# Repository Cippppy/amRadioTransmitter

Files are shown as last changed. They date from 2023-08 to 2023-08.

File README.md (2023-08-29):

# AM Radio Transmitter
This was the final project done for Electronics I by Christian Cipolletta and Thomas Rasa. It is a radio transmitter that will broadcast in the AM band. It uses a Gilbert cell circuit for the mixer, a differential amplifier to combine and strengthen the signal, and an antenna to broadcast it. There is also an MSP430FR2355 Launchpad evaluation board that adds the functionality of changing the tone being broadcast.

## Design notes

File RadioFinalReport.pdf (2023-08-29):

### AM Radio Transmitter: A Gilbert Cell, an Operational Amplifier, and an Antenna

Christian Cipolletta, Thomas Rasa
May 2023

Abstract
This application note described the creation and successful use of an AM radio transmitter circuit. It uses a gilbert cell and a differential amplifier to generate and transmit AM radio waves. The circuit was successful in its simulation and in its prototyping. However, the completed project has a large room for improvement.

Background
The radio is a century old invention that allows for wireless communication by using radio waves. There are two types of waves, amplitude modulation (AM) and frequency modulation (FM). The difference between the two is how the sound information is carried. In the AM band, this is done by varying the amplitude of the signal while in the FM band it is done by varying the frequency of the signal. For this project, we will be focusing on the AM band. There are numerous ways to create a radio transmitter. The one used for this project is a heterodyne transmitter shown in figure
1. A heterodyne is a signal that gets created when mixing two frequencies together. The full circuit includes a low-pass filter (LPF), two amplifiers, the mixer, a bandpass filter (BPF) and an antenna.

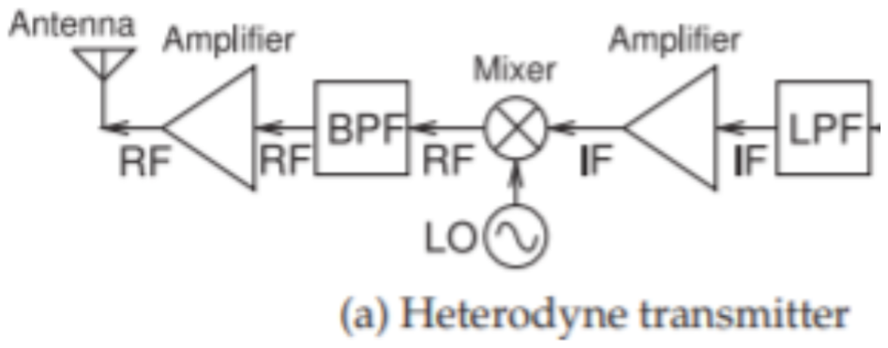
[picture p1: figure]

Figure 1. Heterodyne Transmitter Circuit

For the mixer, we created a circuit called a Gilbert Cell. A Gilbert Cell will create output signals that are proportional to the product of two input signals, which is a different way of saying that it will mix them together. It uses resistors, transistors, and capacitors to create this affect as shown in figure 2. The transfer function of a Gilbert cell is as shown in equation 2

V | (1)

### out = S(ωt) * B(ωt)

Where:
B is the baseband carrier signal
S is the modulating frequency

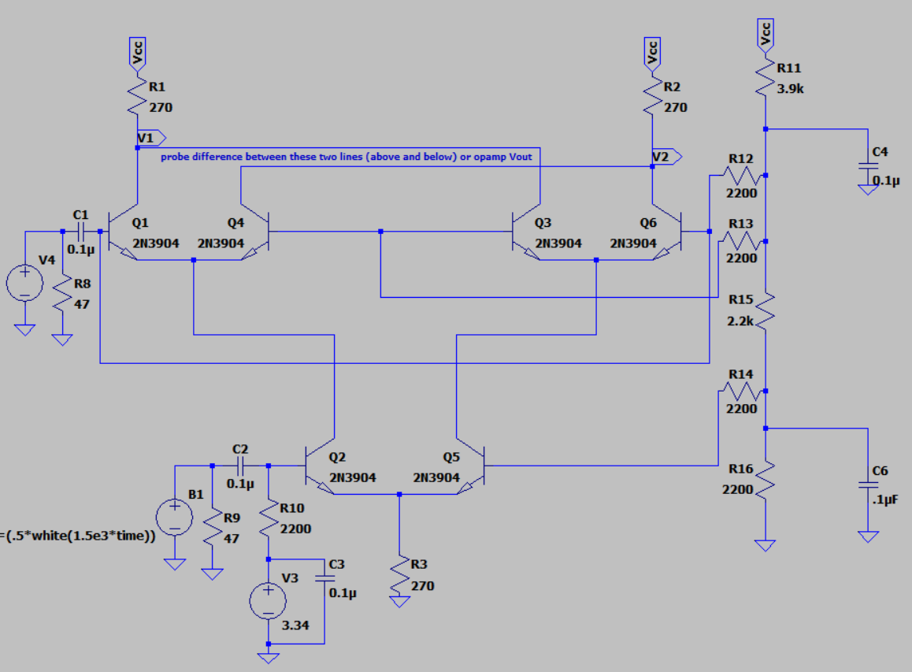
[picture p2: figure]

Figure 2. Gilbert Cell Schematic

For the amplifier circuit, we used a differential operational amplifier topology. In figure 3, R6 and R7 were the same value, and R4 and R5 were the same value to simplify the equation for the gain. This is shown in equation 2.

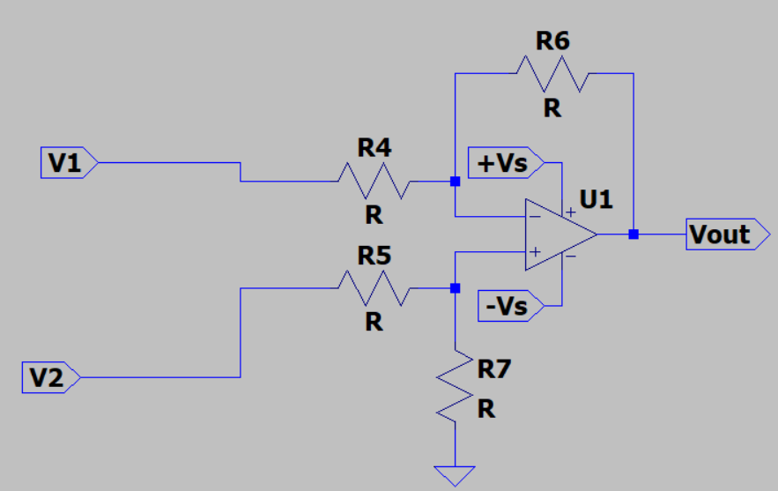
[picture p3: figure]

Figure 3. Dif erential Amplifier Schematic

V

out = (R
3

/R
1

)(V

2 − V
1

)

(2)
Design Constraints
This circuit could be constructed with ease if the world had unlimited resources and each piece was ideal. However, the world is not ideal, so there are constraints that had to be followed when creating this system. First, the system had to be run off of 12VDC or less for safety reasons. Second, it had to have an array of electronic components, specifically modern ones. Third, it had to be low power. Fourth, it had to have a mixed signal/embedded element. Overall, the system had to be edited and unique to fit within these specifications.
One way we fit these constraints is by using an MSP430FR2355 Launch Pad from TI (figure 4). This embedded system would allow us to easily adjust the modulating signal of the AM wave. We used it to specifically make 10 different musical notes that could be played at the touch of a button.

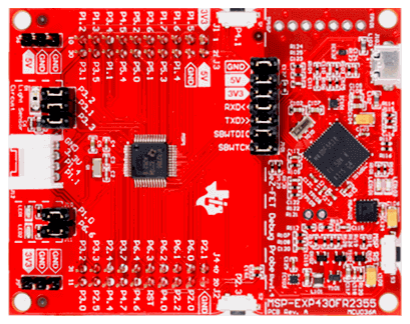
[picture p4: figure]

Figure 4. MSP430FR2355 Launchpad

Approach
The first step of this experiment was to simulate the circuits. It is essential to make sure that the theory works. We did this using the program LTSPICE. We created schematics of each component of the transmitter to ensure that we would be able to get the output signals we expected. This also allowed us to vary any values to see what could be changed in our designs if issues arise later in the process.
The second step is to prototype. We used both bread boards and protoboards to recreate the circuits in real life. Utilizing an oscilloscope, function generator, and power supply we tried to see if the LTSPICE results could be recreated.
The third step was to take any successes from the prototype and redraw the schematic. If there were issues found or improvements that could be made, we made the changes and then re-drew the schematics to make sure the changes were reflected there. With this new schematic, we created a printed circuit board (PCB) that networked all the needed components of the system. The last step was to build and test the PCB. After creating the PCB schematic using a software named Altium, we sent out files to a PCB manufacturer. Once the PCB was received we could then solder all the components onto the PCB. After soldering was completed the radio was ready for final testing.

Results
The results of the LTSPICE simulation are shown in figures 5, 6, and 7. The green and blue plots are the outputs of the gilbert cell circuit. They form a nice radio wave as expected. The red plot is the output of the differential amplifier. It is what is the final signal that would be transmitted to radio receivers.

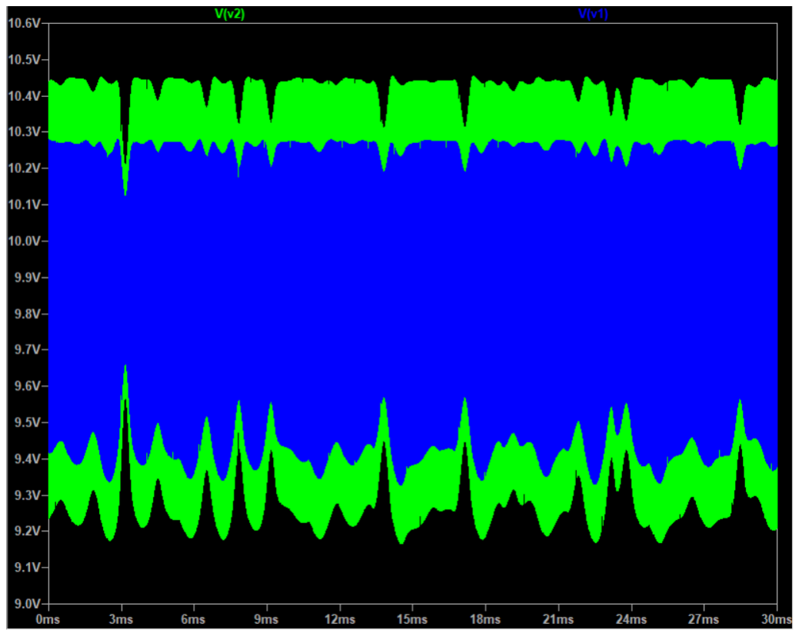
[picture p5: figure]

Figure 5. LTSPICE output of gilbert cell circuit

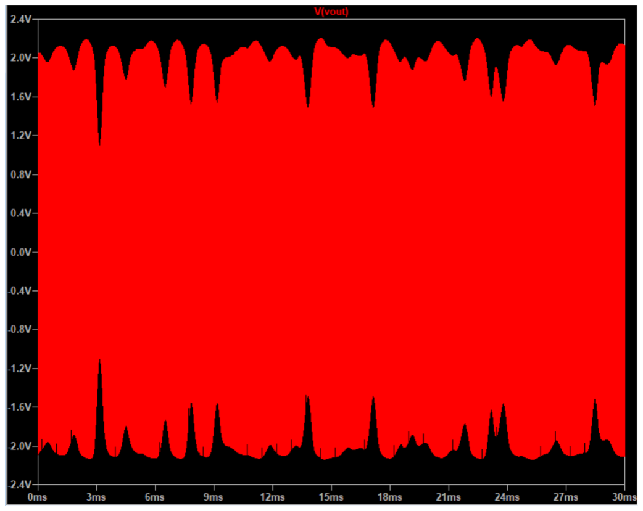
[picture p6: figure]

Figure 6. LTSPICE output of dif erential amplifier

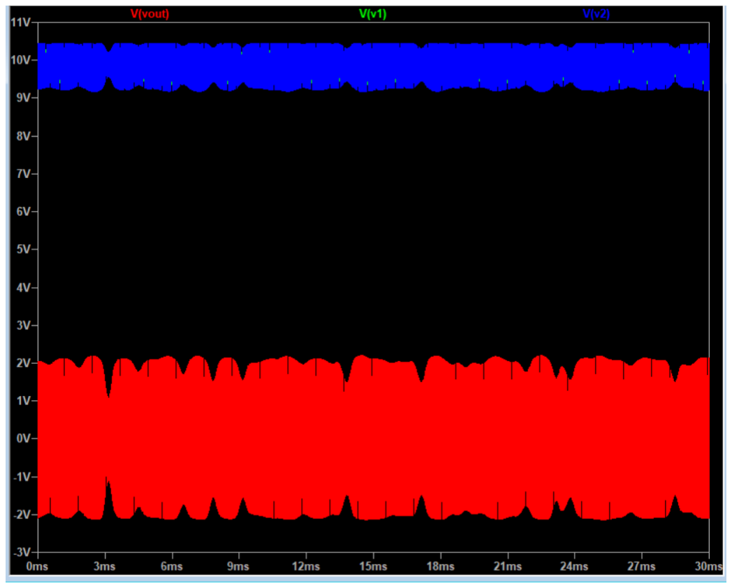
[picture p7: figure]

Figure 7. Combined LTSPICE output

Results from the breadboard prototype of the gilbert cell circuit are shown in figure 8. This also is the expected result. It gives a waveform that is characteristic of AM radio waves. The results from the differential amplifier were not pictured, but they were as expected too.

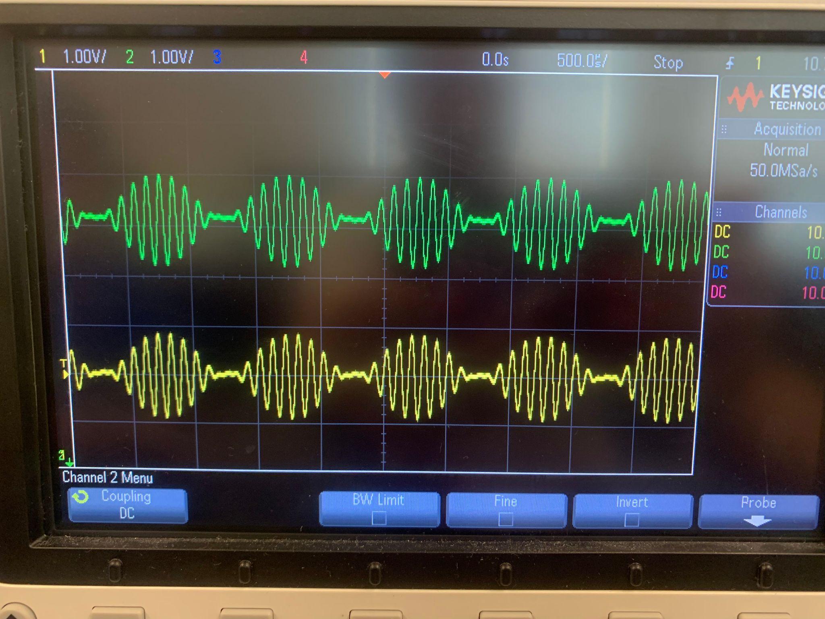
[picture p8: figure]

Figure 8. Prototype Output on oscilloscope

The fully soldered PCB is shown in figure 9. The gilbert cell circuit is soldered at the bottom of the PCB along with the operational amplifier. The potentiometer at the top of the board is there to try and create an offset for the unipolar op-amp we created. The jumpers are where we are able to hook up external function generators, power supplies, and the MSP430. The last part of the board, located at the bottom, is a coaxial SMA hookup that connects to the antenna.

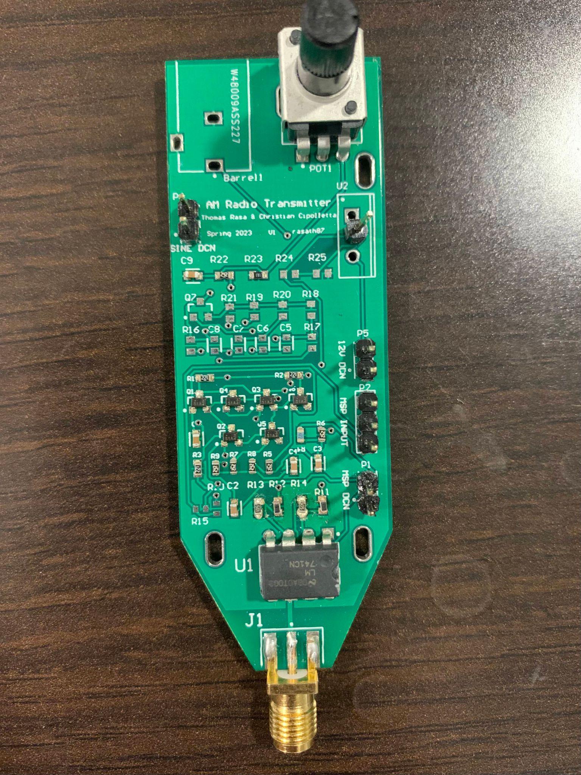
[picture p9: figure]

Figure 9. Final Soldered PCB

Discussion
The final product functioned within acceptable limits for the time constraints we were working under.. The simulations had promising results that were reflected in the prototype and PCB. When the power was supplied to the circuit, we were able to receive the transmission through a battery-powered radio receiver. The MSP430 was successfully able to change the note being received by the radio as well. It was a success as a proof of concept, but there are places where it can be improved.
In the future, there are some improvements to be made. First, we would like to have a working sine wave generator. This way we would not have to hook the system up to a function generator, and rather just a power source like a battery or the wall. Second, we would like to build an antenna that is better tuned with the frequency we transmit at. The antennas we had access to are tuned for the FM band which reduces the gain we can achieve since we are transmitting in the AM band. Lastly, we would like to understand why our unipolar op-amp is not giving a large gain like we had designed it to.

References

[1] W. Storr, “Differential amplifier - the voltage subtractor,” Basic Electronics Tutorials, https://www.electronics-tutorials.ws/opamp/opamp_5.html (accessed May 9, 2023).
[2] R. Mancini, Texas Instruments, Dallas, Texas, rep., 2001

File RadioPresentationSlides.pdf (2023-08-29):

# AM Radio Transmitter

## Thomas Rasa & Christian Cipolletta

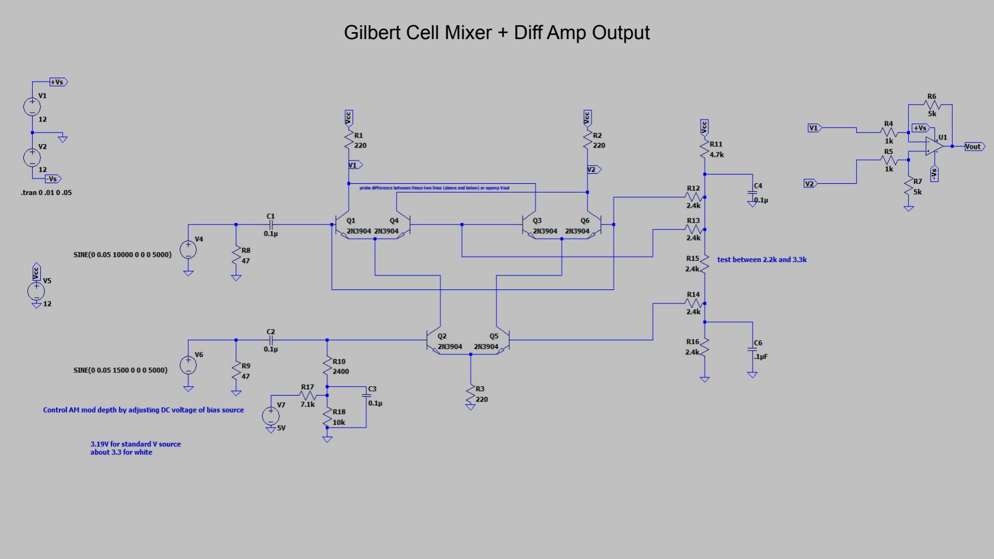
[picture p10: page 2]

Gilbert Cell Mixer + Diff Amp Output

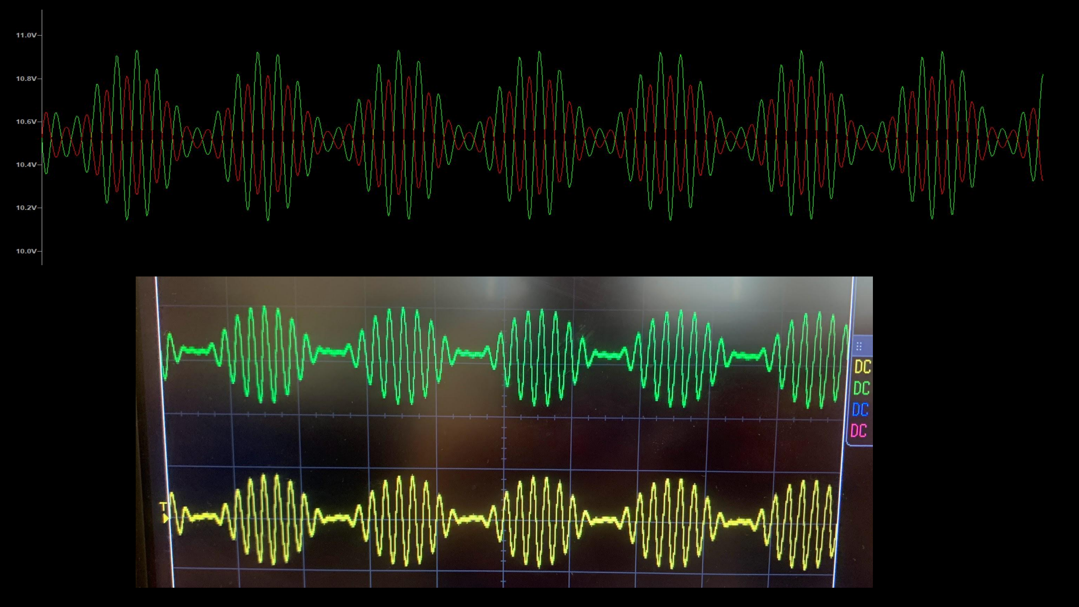
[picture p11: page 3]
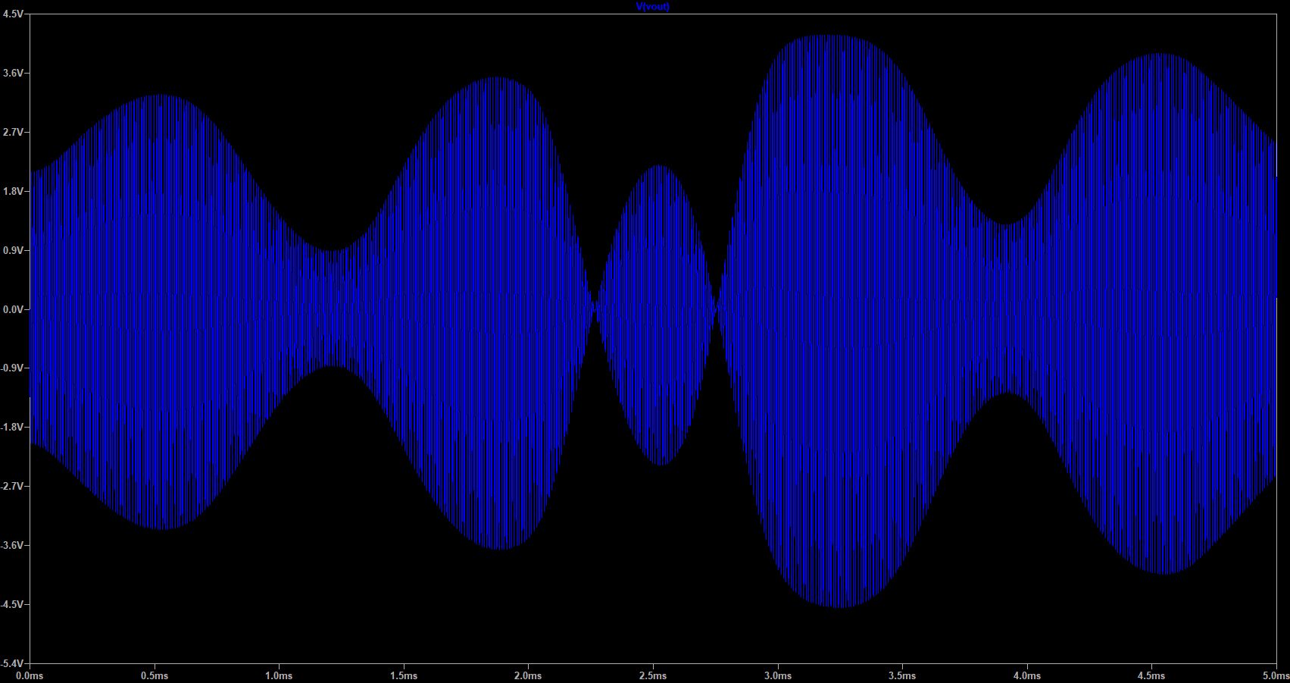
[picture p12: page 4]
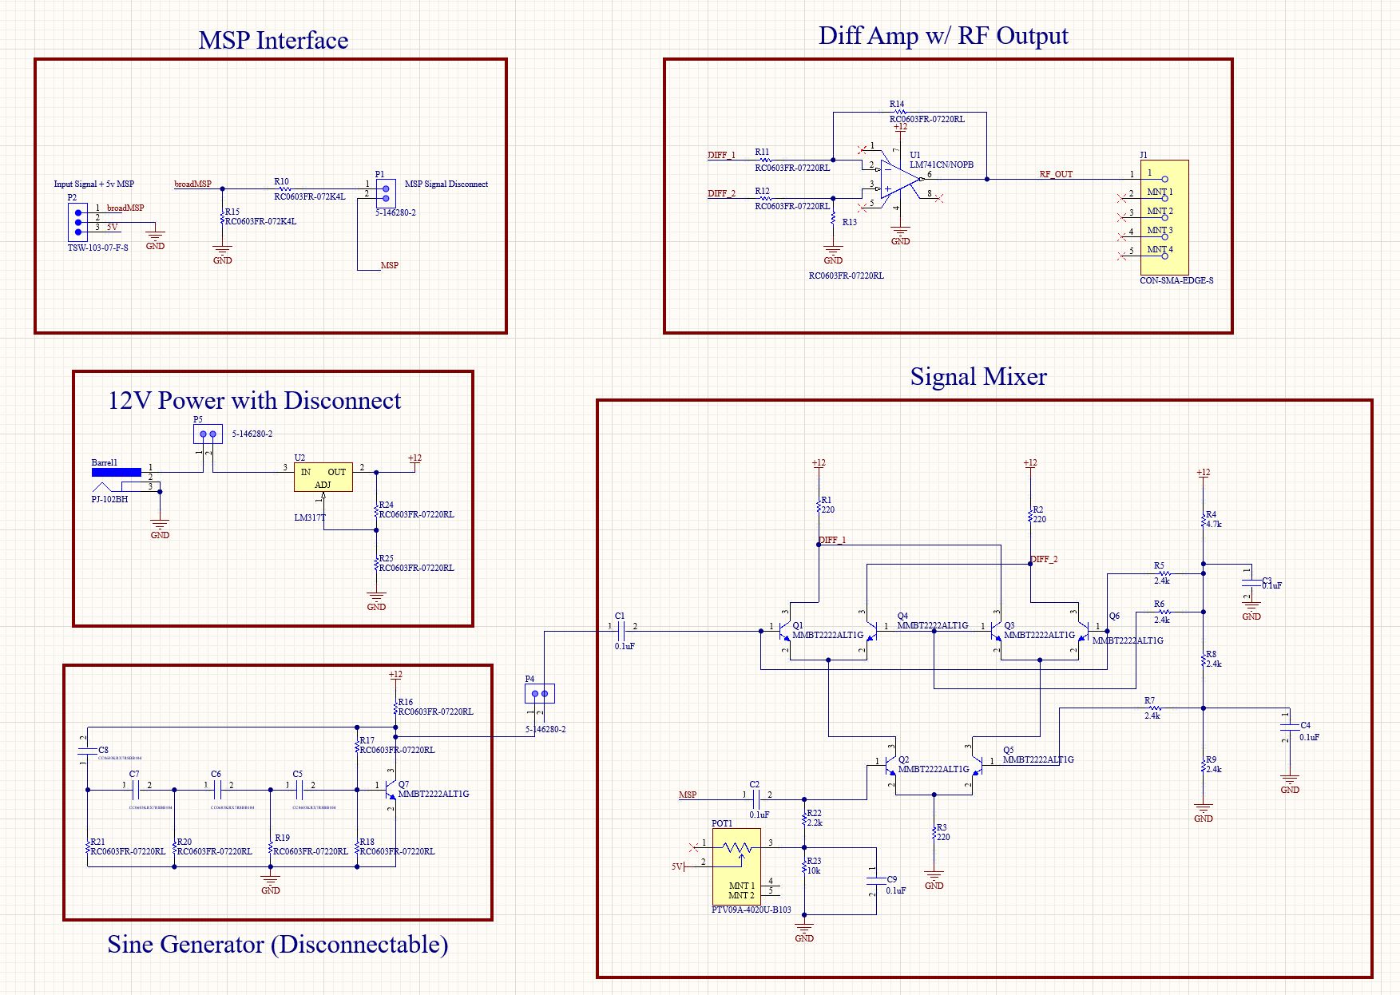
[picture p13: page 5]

## PCB

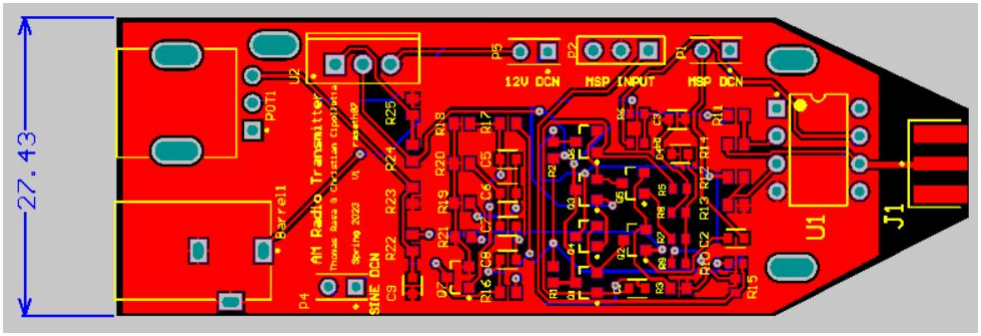
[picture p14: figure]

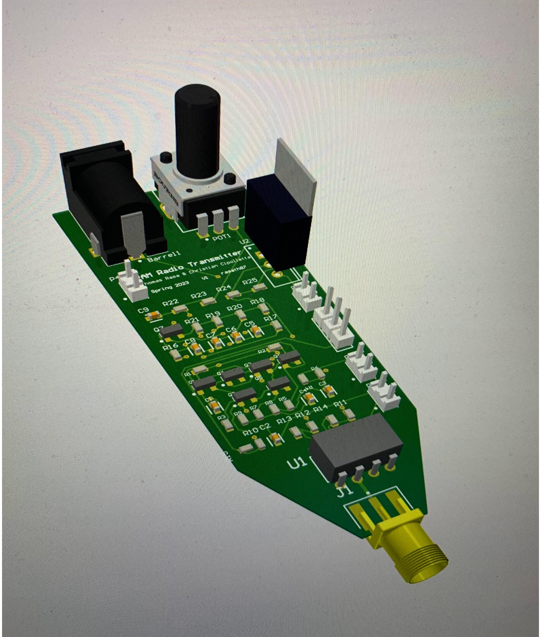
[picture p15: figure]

## PCB

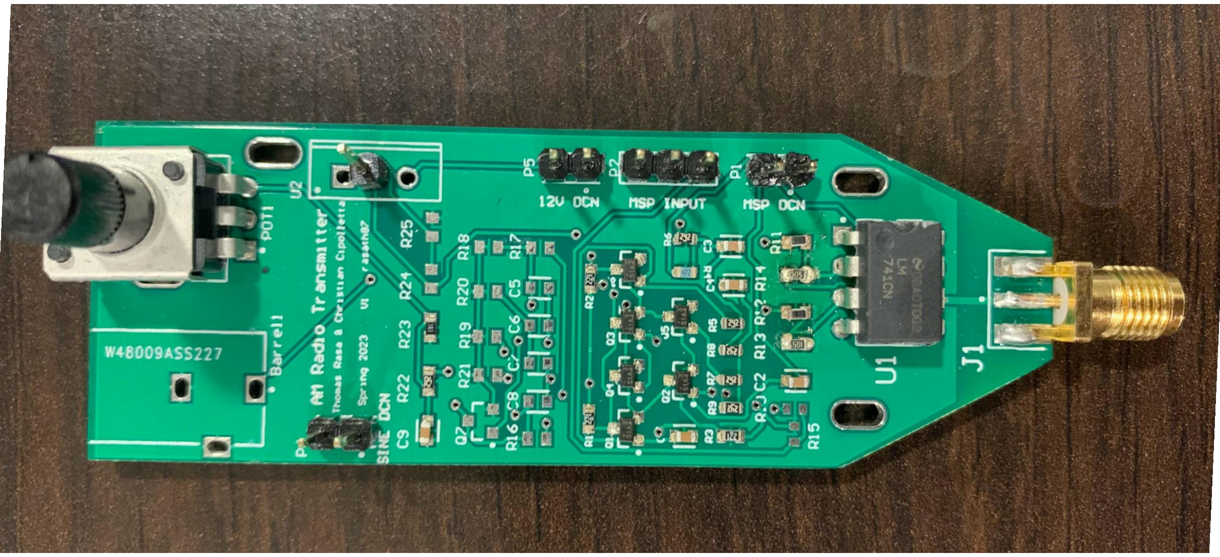
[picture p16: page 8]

## Working Parts

- Able to transmit an AM Radio Wave
- The MSP430 generates the broadcast signal while a function generator makes the carrier wave
- Able to change the broadcast signal with the press of a keyboard button
- Able to receive the AM wave using an AM Radio

## Works in Progress

- The carrier signal generator circuit only generates a wave with a frequency of 80MHz
- The differential amplifier has little to no gain
- The antennas being used are not made for the AM Band

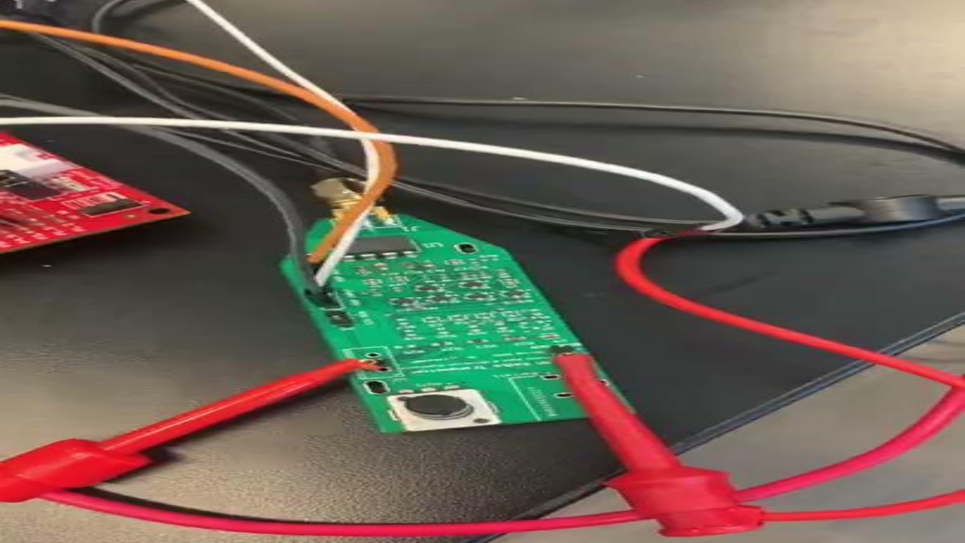
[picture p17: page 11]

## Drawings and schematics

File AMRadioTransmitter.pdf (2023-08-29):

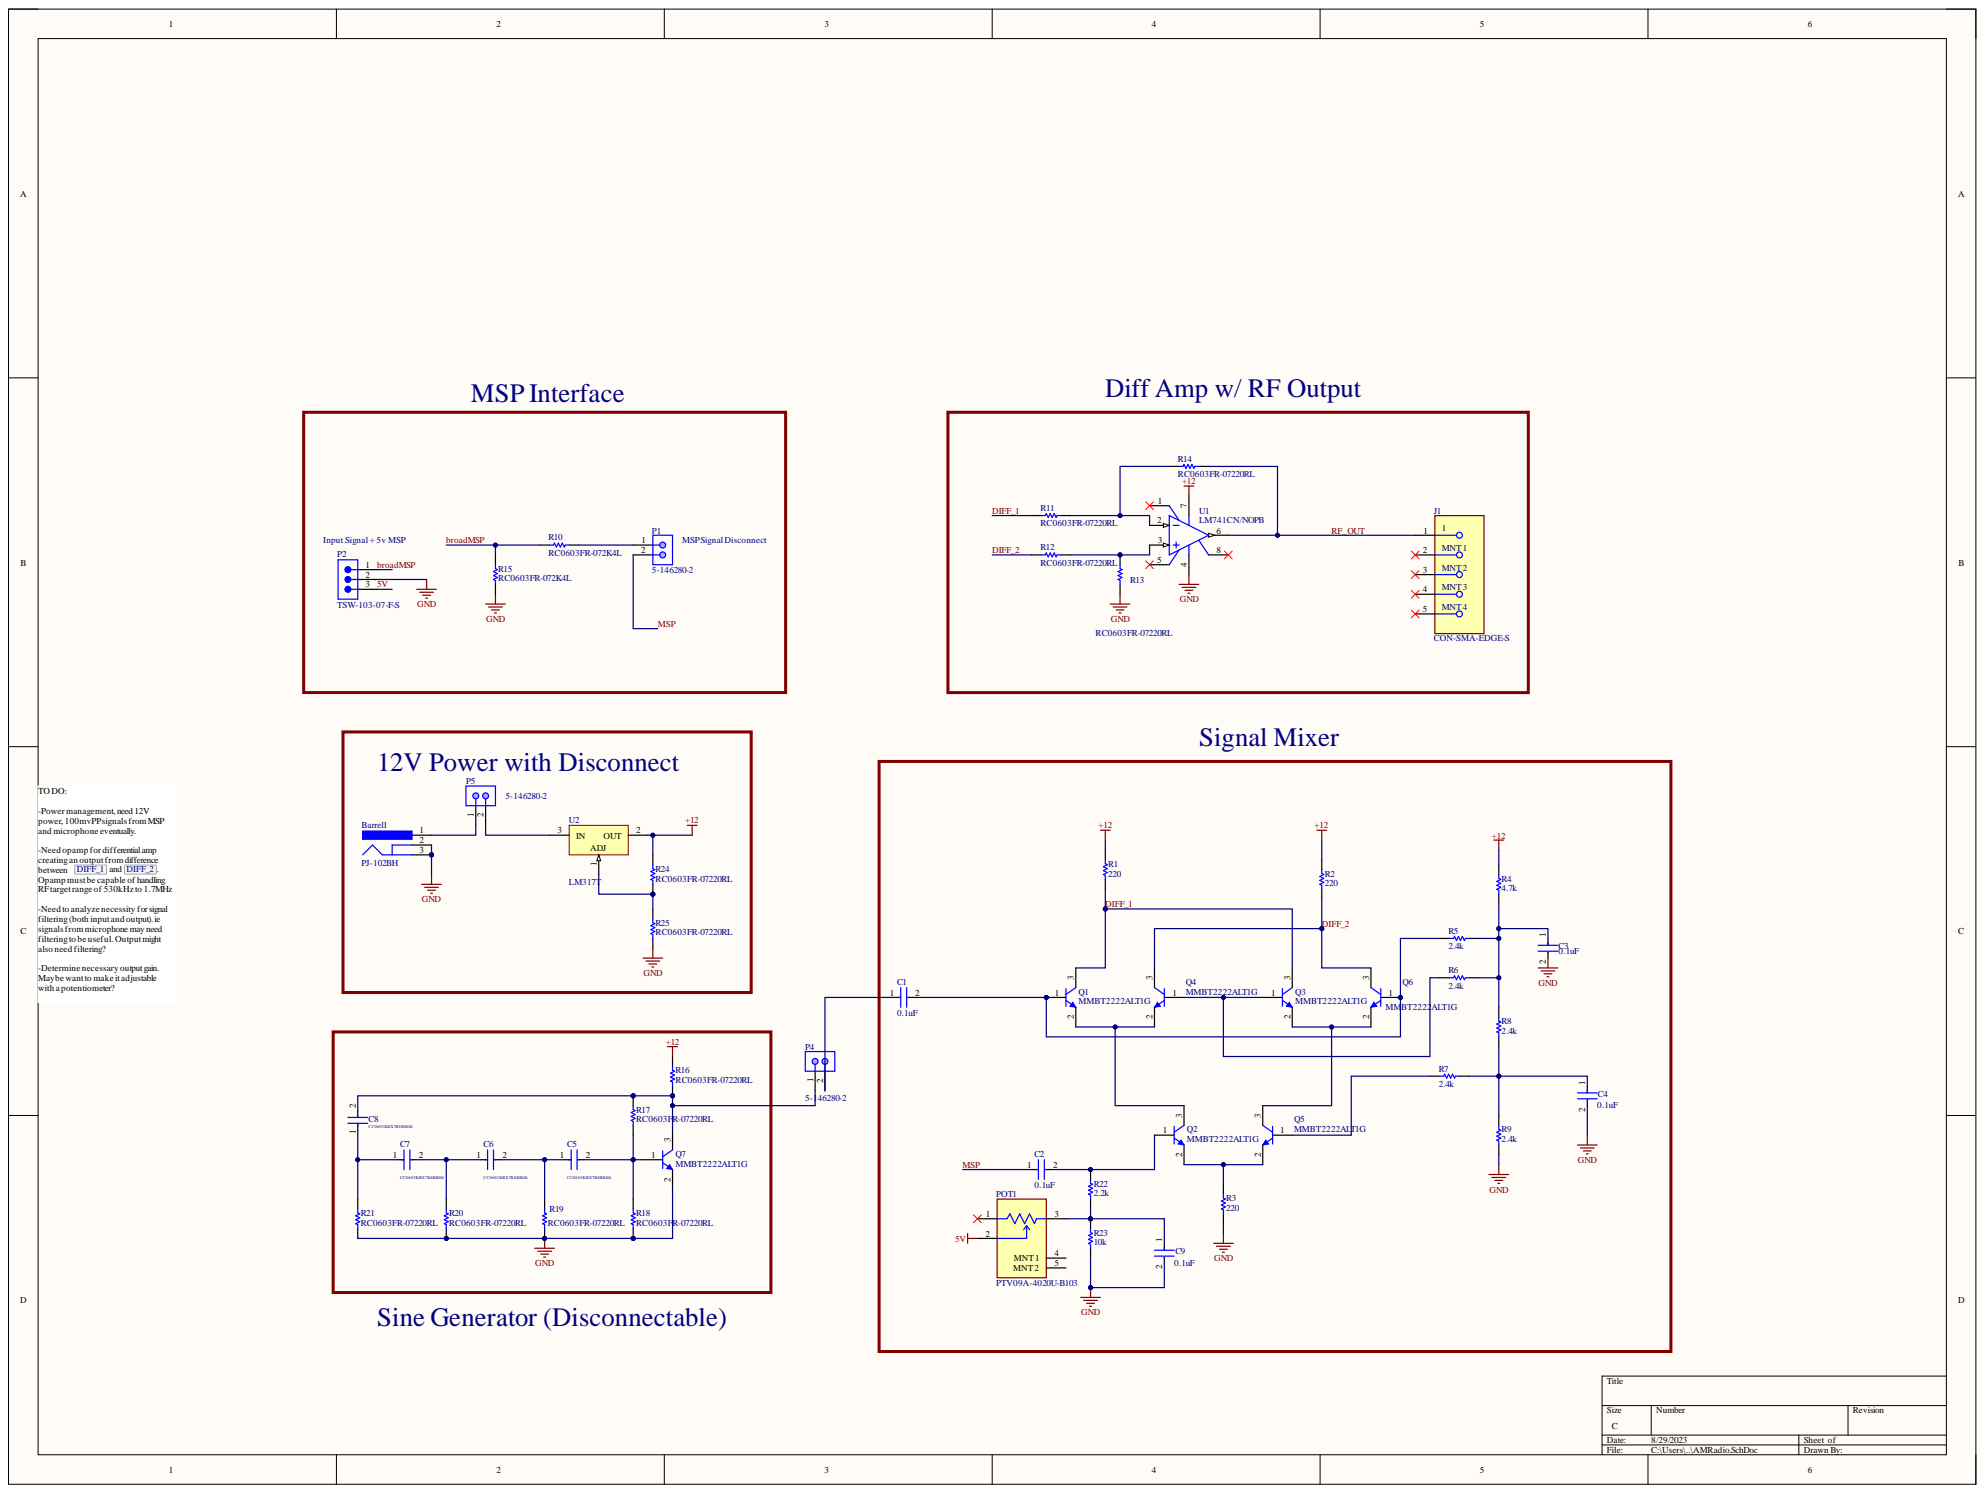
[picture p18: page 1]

Diff Amp w/ RF Output

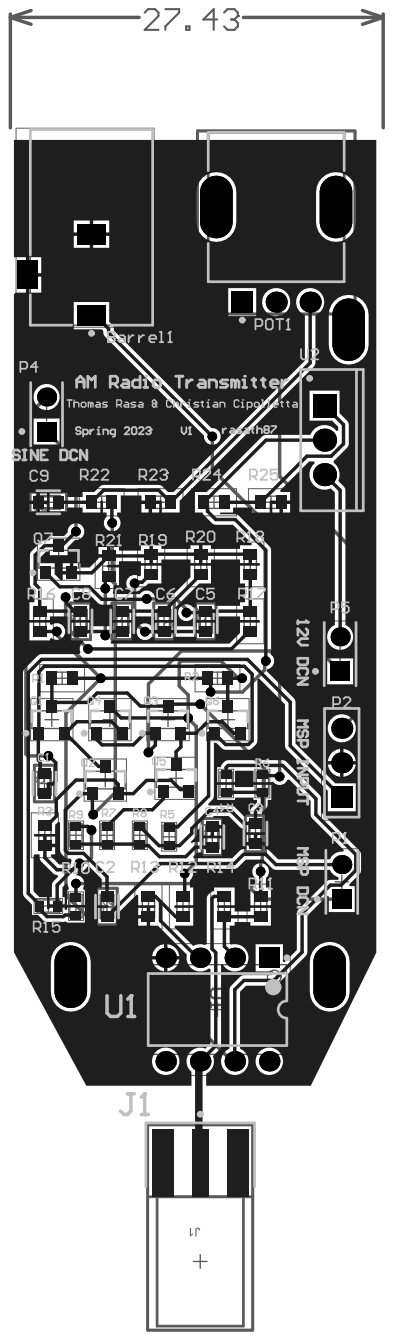
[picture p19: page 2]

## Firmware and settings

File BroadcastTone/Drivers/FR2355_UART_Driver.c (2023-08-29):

/*
 * FR2355_UART.c
 *
 *  Created on: Dec 7, 2022
 *      Author: traffo17
 */

#include <msp430.h>
#include "FR2355_UART_Driver.h"


/**
 * UART Init for 9600 Baud
 */

void uart_Init_9600(){
    PM5CTL0 &= ~LOCKLPM5;                    // Disable the GPIO power-on default high-impedance mode
                                              // to activate 1previously configured port settings

     __bis_SR_register(SCG0);                 // disable FLL
     CSCTL3 |= SELREF__REFOCLK;               // Set REFO as FLL reference source
     CSCTL1 = DCOFTRIMEN_1 | DCOFTRIM0 | DCOFTRIM1 | DCORSEL_3;// DCOFTRIM=3, DCO Range = 8MHz
     CSCTL2 = FLLD_0 + 243;                  // DCODIV = 8MHz
     __delay_cycles(3);
     __bic_SR_register(SCG0);                // enable FLL
     Software_Trim();                        // Software Trim to get the best DCOFTRIM value

     CSCTL4 = SELMS__DCOCLKDIV | SELA__REFOCLK; // set default REFO(~32768Hz) as ACLK source, ACLK = 32768Hz
                                              // default DCODIV as MCLK and SMCLK source



     // Configure UART
     UCA1CTLW0 |= UCSWRST;
     UCA1CTLW0 |= UCSSEL__SMCLK;

     // Baud Rate calculation
     // 8000000/(16*9600) = 52.083
     // Fractional portion = 0.083
     // User's Guide Table 17-4: UCBRSx = 0x49
     // UCBRFx = int ( (52.083-52)*16) = 1
     UCA1BR0 = 52;                             // 8000000/16/9600
     UCA1BR1 = 0x00;
     UCA1MCTLW = 0x4900 | UCOS16 | UCBRF_1;

     UCA1CTLW0 &= ~UCSWRST;                    // Initialize eUSCI
     UCA1IE |= UCRXIE;                         // Enable USCI_A0 RX interrupt

}

/**
 * UART Software Trim
 * Used to trim the oscillator within the USCI peripheral to match the exact clock.
 */

void Software_Trim()
{
    unsigned int oldDcoTap = 0xffff;
    unsigned int newDcoTap = 0xffff;
    unsigned int newDcoDelta = 0xffff;
    unsigned int bestDcoDelta = 0xffff;
    unsigned int csCtl0Copy = 0;
    unsigned int csCtl1Copy = 0;
    unsigned int csCtl0Read = 0;
    unsigned int csCtl1Read = 0;
    unsigned int dcoFreqTrim = 3;
    unsigned char endLoop = 0;

    do
    {
        CSCTL0 = 0x100;                         // DCO Tap = 256
        do
        {
            CSCTL7 &= ~DCOFFG;                  // Clear DCO fault flag
        }while (CSCTL7 & DCOFFG);               // Test DCO fault flag

        __delay_cycles((unsigned int)3000 * MCLK_FREQ_MHZ);// Wait FLL lock status (FLLUNLOCK) to be stable
                                                           // Suggest to wait 24 cycles of divided FLL reference clock
        while((CSCTL7 & (FLLUNLOCK0 | FLLUNLOCK1)) && ((CSCTL7 & DCOFFG) == 0));

        csCtl0Read = CSCTL0;                   // Read CSCTL0
        csCtl1Read = CSCTL1;                   // Read CSCTL1

        oldDcoTap = newDcoTap;                 // Record DCOTAP value of last time
        newDcoTap = csCtl0Read & 0x01ff;       // Get DCOTAP value of this time
        dcoFreqTrim = (csCtl1Read & 0x0070)>>4;// Get DCOFTRIM value

        if(newDcoTap < 256)                    // DCOTAP < 256
        {
            newDcoDelta = 256 - newDcoTap;     // Delta value between DCPTAP and 256
            if((oldDcoTap != 0xffff) && (oldDcoTap >= 256)) // DCOTAP cross 256
                endLoop = 1;                   // Stop while loop
            else
            {
                dcoFreqTrim--;
                CSCTL1 = (csCtl1Read & (~DCOFTRIM)) | (dcoFreqTrim<<4);
            }
        }
        else                                   // DCOTAP >= 256
        {
            newDcoDelta = newDcoTap - 256;     // Delta value between DCPTAP and 256
            if(oldDcoTap < 256)                // DCOTAP cross 256
                endLoop = 1;                   // Stop while loop
            else
            {
                dcoFreqTrim++;
                CSCTL1 = (csCtl1Read & (~DCOFTRIM)) | (dcoFreqTrim<<4);
            }
        }

        if(newDcoDelta < bestDcoDelta)         // Record DCOTAP closest to 256
        {
            csCtl0Copy = csCtl0Read;
            csCtl1Copy = csCtl1Read;
            bestDcoDelta = newDcoDelta;
        }

    } while(endLoop == 0);                      // Poll until endLoop == 1

    CSCTL0 = csCtl0Copy;                       // Reload locked DCOTAP
    CSCTL1 = csCtl1Copy;                       // Reload locked DCOFTRIM
    while(CSCTL7 & (FLLUNLOCK0 | FLLUNLOCK1)); // Poll until FLL is locked
}




/** uart_Print(char *InputString)
 * Sends a STRING over UART using polling. Note that the input is a pointer to a character array which is NULL terminated
 * Input: pointer to char array with NULL termination.
 *
 * Requires uart_Init_9600 to be run prior to using this function.
 */
void uart_Print(char *InputString){
    while(*InputString != 0) {
        while (!(UCA1IFG&UCTXIFG));
        UCA1TXBUF = *InputString++;
    }
    while (!(UCA1IFG&UCTXIFG));
    UCA1TXBUF = 0x0A;
    while (!(UCA1IFG&UCTXIFG));
    UCA1TXBUF = 0x0D;
}

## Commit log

2023-08-29 Add Altium Files
    [AMRadio.PcbDoc, AMRadio.SchDoc]
2023-08-29 Add MSP430 code, Delete uneeded Altium files
    [FR2355_UART_Driver.obj, GPIO_Driver.obj, RADIO.PcbDoc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]
